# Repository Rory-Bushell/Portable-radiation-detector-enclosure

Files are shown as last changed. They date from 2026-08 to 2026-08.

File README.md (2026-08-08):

# Portable Radiation Detector Enclosure

A rugged, portable enclosure designed to house a Geiger-Müller radiation
sensor (SBM-20) for emergency-response field use — balancing impact and
environmental protection with the need to keep the sensor's detection
window functional.

**Overall dimensions:** 120mm x 170mm x 205mm

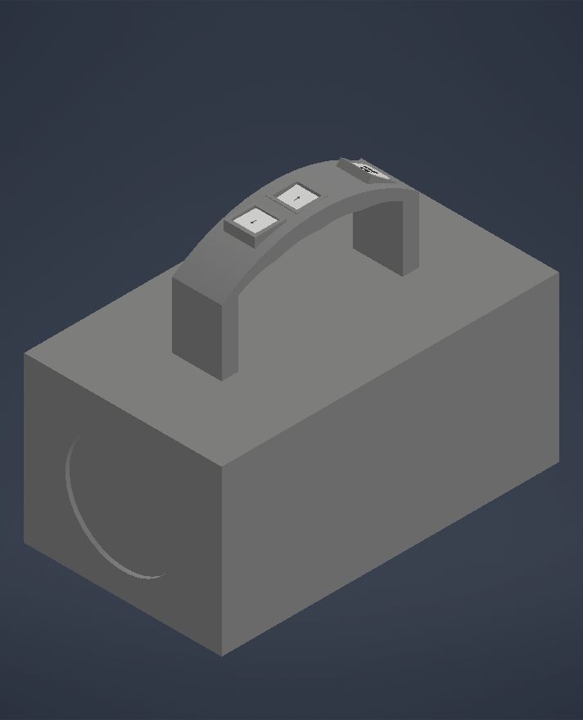
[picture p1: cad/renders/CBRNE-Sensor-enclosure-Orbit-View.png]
Isometric view


## Methodology

| Stage | Method |
|---|---|
| Design requirements | Defined against IP66/67 (environmental sealing), IK-rated impact resistance, and MIL-STD-810G drop-test conventions for portable field equipment |
| Material selection | Granta EduPack Ashby chart comparison — shortlisted candidates for the main shell, sensor window, and threaded cap against density, fracture toughness, temperature, and price constraints |
| CAD design | Autodesk Inventor Professional — full assembly including sealed access hatch, threaded USB-C charging cap with O-ring seal, and internal component layout |
| Packaging validation | Internal layout checked against real component dimensions — SBM-20 tube (108 x 11mm), 50 x 30mm driver PCB, 40 x 30 x 5mm LiPo pouch cell — within an 11.34mm internal clearance constraint |

## Key design decisions

- **1.5mm sensor detection window** (vs. 4mm main shell wall) — minimises
  radiation attenuation directly in front of the sensor, while the rest of
  the shell stays thicker for impact protection. See cross-section render
  below.
- **Threaded USB-C charging cap with O-ring seal**, mounted on the rear face,
  away from the sensor window — keeps the sealed detection face permanently
  undisturbed during charging or servicing
- **LiPo pouch cell over AA batteries** — driven by a strict 11.34mm internal
  clearance constraint; traded field battery-swapping for sealed USB-C
  recharging
- **Consistent polypropylene material family** across the shell, window, and
  cap, differing only in reinforcement type/level — see
  [`materials/material_comparison.md`](materials/material_comparison.md)
  for full Granta EduPack justification

## Environmental sealing

Designed against **IP66/67** (dust-tight, protected against water jets and
temporary immersion) — the standard ingress protection benchmark for
outdoor, field-deployed electronics — using three sealing points:

- **O-ring seal on the sensor window**, bonded into the shell, keeping the
  detection face permanently watertight without relying on a removable joint
- **O-rings under each of the three control buttons**, compressed by the
  button against the shell to seal the button aperture while still allowing
  tactile actuation
- **O-ring seal on the threaded USB-C cap**, compressed as the cap is
  screwed down, sealing the only access point into the electronics
  compartment

Keeping every seal a static, compressed O-ring joint (rather than an
adhesive or gasket-tape seal) means each one can be inspected and, if
necessary, replaced individually without affecting the others.

## Engineering trade-offs

Key constraints encountered during the design, and the decisions made to
address them:

| Constraint | Decision | Trade-off accepted |
|---|---|---|
| Sensor needs radiation reaching it from all sides | Window wall reduced to 1.5mm vs. 4mm shell | Window is the weakest point for impact — mitigated by keeping it small and centrally supported |
| 11.34mm internal clearance between sensor and base | Switched from AA cells to a 40x30x5mm LiPo pouch cell | Lost field battery-swapping; gained a much smaller footprint, recharged via sealed USB-C |
| Cap needs repeated hand-tightening without cross-threading | Coarse M24 x 1.5 ISO metric thread, non-directional glass-mat-reinforced PP | Slightly heavier/less optimised than a fine-pitch thread, but far more tolerant of field handling |
| Sensing element (SBM-20) is a hobbyist-grade component, not an industrial detector | Used as a realistic stand-in, with the limitation stated explicitly (see Note on scope) | Project demonstrates enclosure design methodology rather than detector performance |

## Renders

| View | Description |
|---|---|
| Isometric | Isometric hero view — full assembled enclosure |
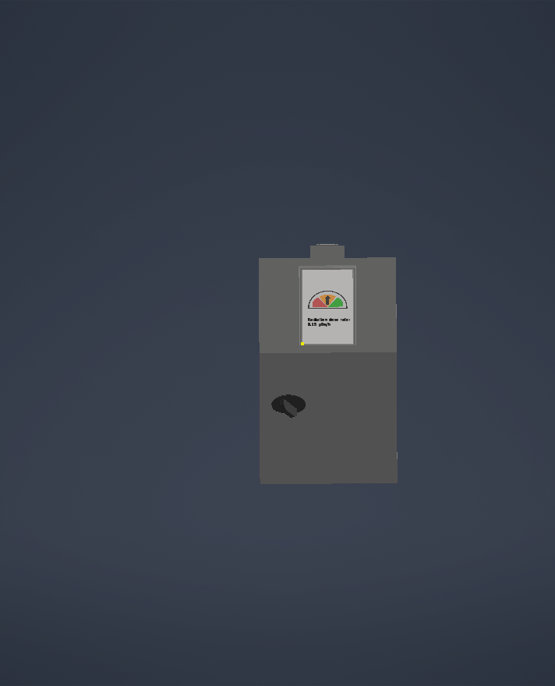
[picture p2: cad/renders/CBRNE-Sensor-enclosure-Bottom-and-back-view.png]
Back and base
|  | Rear/base view — digital display and charging cap |
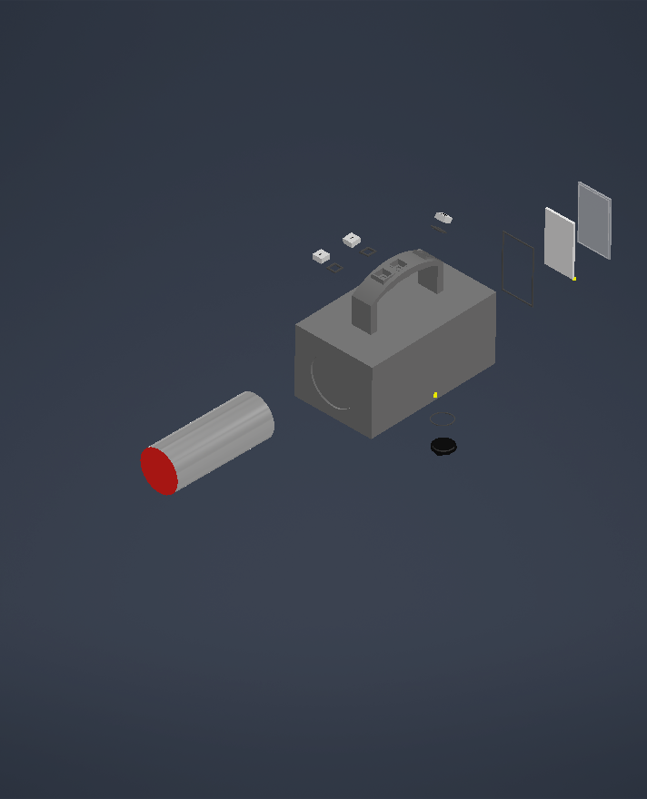
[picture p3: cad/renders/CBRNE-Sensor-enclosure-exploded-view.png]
Exploded view
|  | Exploded assembly — shell, sensor, PCB, battery, cap |
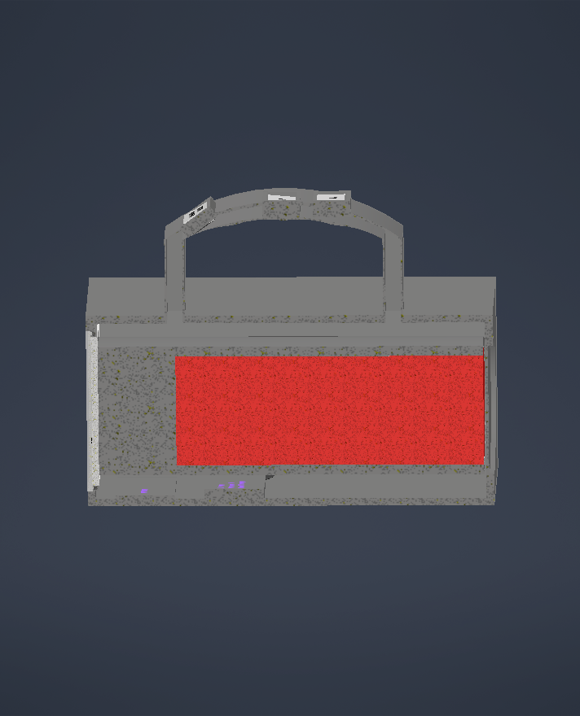
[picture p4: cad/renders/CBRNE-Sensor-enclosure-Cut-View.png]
Cross-section
|  | Cross-section through the sensor window, showing the 1.5mm window wall vs. 4mm shell wall |
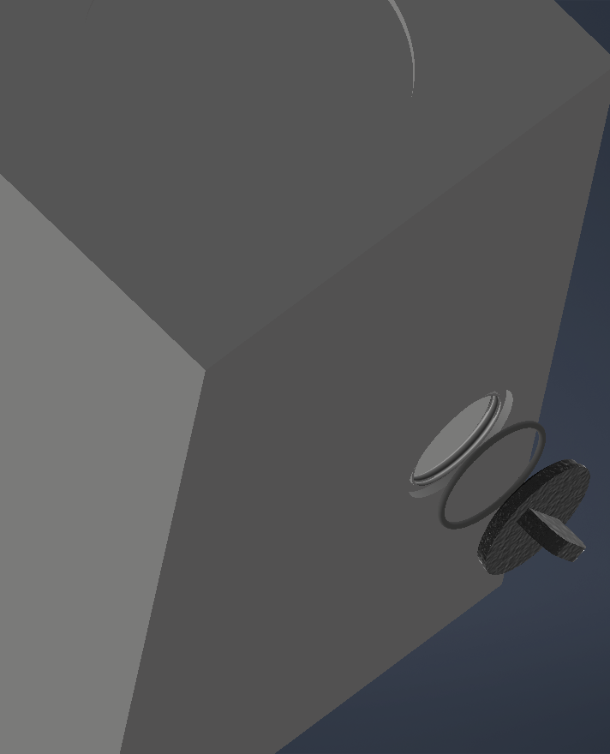
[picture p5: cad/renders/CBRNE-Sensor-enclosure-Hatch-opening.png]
Cap detail
|  | Close-up of the threaded USB-C cap and O-ring seal |

## Materials

Full property data and justification per component:
[`materials/material_comparison.md`](materials/material_comparison.md)

Ashby charts (Fracture Toughness vs. Density) used to shortlist each
component's material — click a link to view the chart at full size:

| Component | Chart |
|---|---|
| Main shell | [View chart](materials/Ashby-chart-Main-Casing.png) |
| Threaded cap | [View chart](materials/Ashby-chart-Opening-hatch.png) |
| Sensor window | [View chart](materials/Ashby-chart-Radiation-window.png) |

## Repository contents

```
cad/
├── CBRNE-sensor-enclosure.stp                  Universally-viewable 3D model
└── renders/
    ├── CBRNE-Sensor-enclosure-Orbit-View.png
    ├── CBRNE-Sensor-enclosure-Bottom-and-back-view.png
    ├── CBRNE-Sensor-enclosure-exploded-view.png
    ├── CBRNE-Sensor-enclosure-Cut-View.png
    └── CBRNE-Sensor-enclosure-Hatch-opening.png
drawings/
└── CBRNE-Sensor-enclosure-Assembly-Drawings.pdf   Dimensioned technical drawing
materials/
├── material_comparison.md                      Granta EduPack property data + justification
├── Ashby-chart-Main-Casing.png
├── Ashby-chart-Opening-hatch.png
└── Ashby-chart-Radiation-window.png
```

**Viewing the STEP file:** GitHub does not render 3D files directly — clicking
the `.stp` file shows raw text. Open it in Inventor, Fusion 360, FreeCAD, or
a free online viewer such as [3dviewer.net](https://3dviewer.net) to view it
interactively.

## Note on scope

This project uses a real, well-documented, low-cost Geiger-Müller tube
(SBM-20) as the sensing element. Industrial radiation portal monitors
typically use scintillator-based detectors (e.g. NaI, plastic scintillators)
meeting standards such as ANSI N42.35 and IEC 62244. The focus of this
project is the mechanical and materials engineering challenge of enclosure
design — protecting a radiation-sensitive component without compromising its
detection capability — not the development of detector technology itself,
and it has not been validated against formal CBRNE testing standards.

## Relevance

Directly engages with radiological detection/sensing technology and
critical infrastructure protection themes, applying materials science
(Granta EduPack) and mechanical design (Inventor) to a real security
engineering constraint: protecting sensitive detection equipment in the
field.

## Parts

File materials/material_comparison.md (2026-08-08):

# Material Selection Summary

Selected via Granta EduPack Level 3 Eco Design database, using a
Fracture Toughness vs. Density Ashby chart methodology, filtered against
component-specific density, fracture toughness, operating temperature bounds, and price constraints.

## Main shell — PP (homopolymer, 30% glass fibre)

| Property | Value |
|---|---|
| Density | 0.0403 – 0.041 lb/in³ |
| Fracture toughness | 2.71 – 4.96 ksi·√in |
| Price | 0.767 – 0.916 USD/lb |

**Justification:** Best combination of low density and high fracture
toughness among candidates passing the shell's constraint set — outperformed
all other options on both axes simultaneously.

## Sensor detection window — PP (homopolymer, clarified/nucleated)

| Property | Value |
|---|---|
| Density | 0.0325 – 0.0328 lb/in³ |
| Fracture toughness | 2.09 – 2.2 ksi·√in |
| Price | 1.01 – 1.3 USD/lb |

**Justification:** Lowest density among viable candidates, prioritising
radiation transparency at the detection face, while retaining adequate
toughness for a thin (1.5mm) protective panel.

## Threaded USB-C cap — PP molding compound (40% random glass mat)

| Property | Value |
|---|---|
| Density | 0.0426 – 0.0434 lb/in³ |
| Fracture toughness | 12.6 – 15.5 ksi·√in |
| Price | 1.63 – 1.89 USD/lb |

**Justification:** Highest fracture toughness among realistic, non-directional
candidates — suited to a small part enduring repeated hand-tightening and
occasional drops.

## Note

All three selected materials are from the polypropylene family, differing
only in reinforcement type/level — a deliberate, consistent material
strategy across the enclosure rather than unrelated material choices per
component.

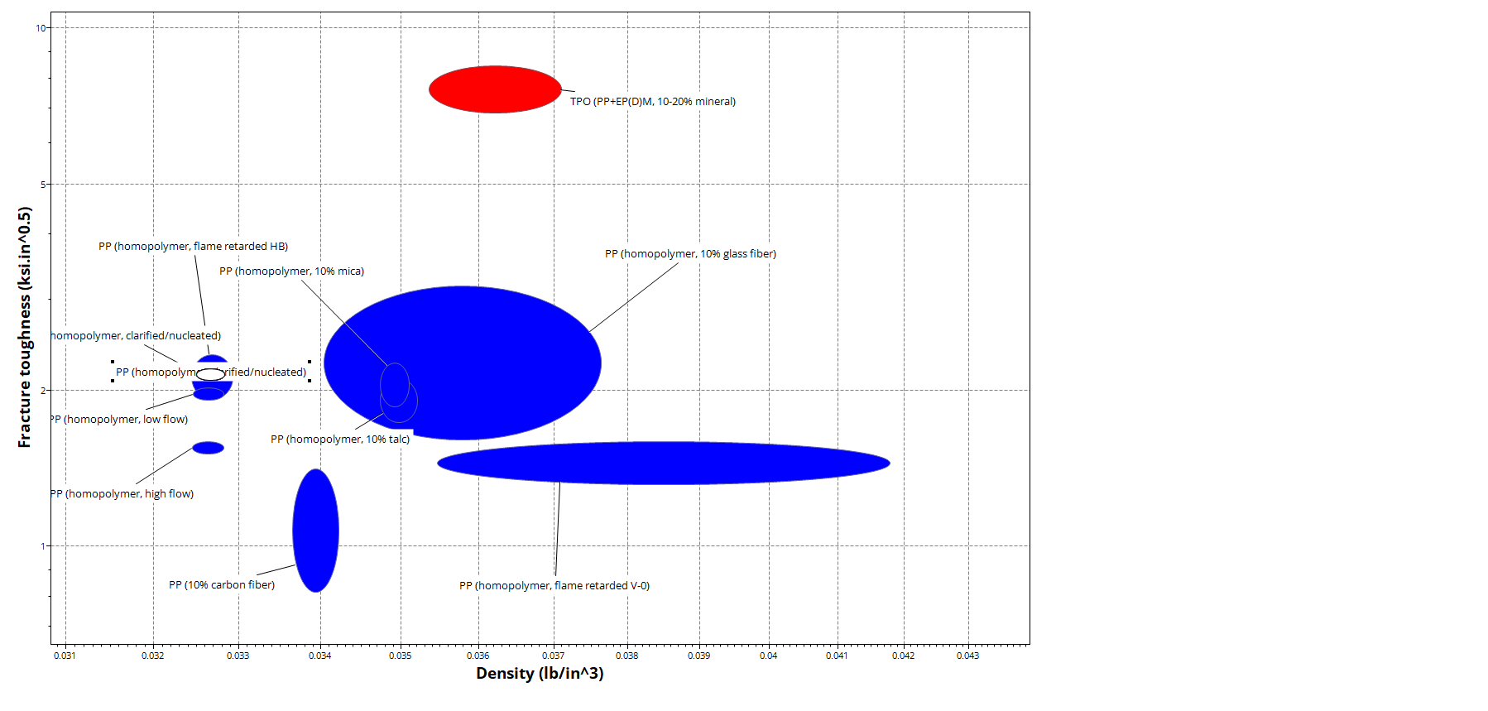
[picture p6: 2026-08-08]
materials/Ashby-chart-Radiation-window.png

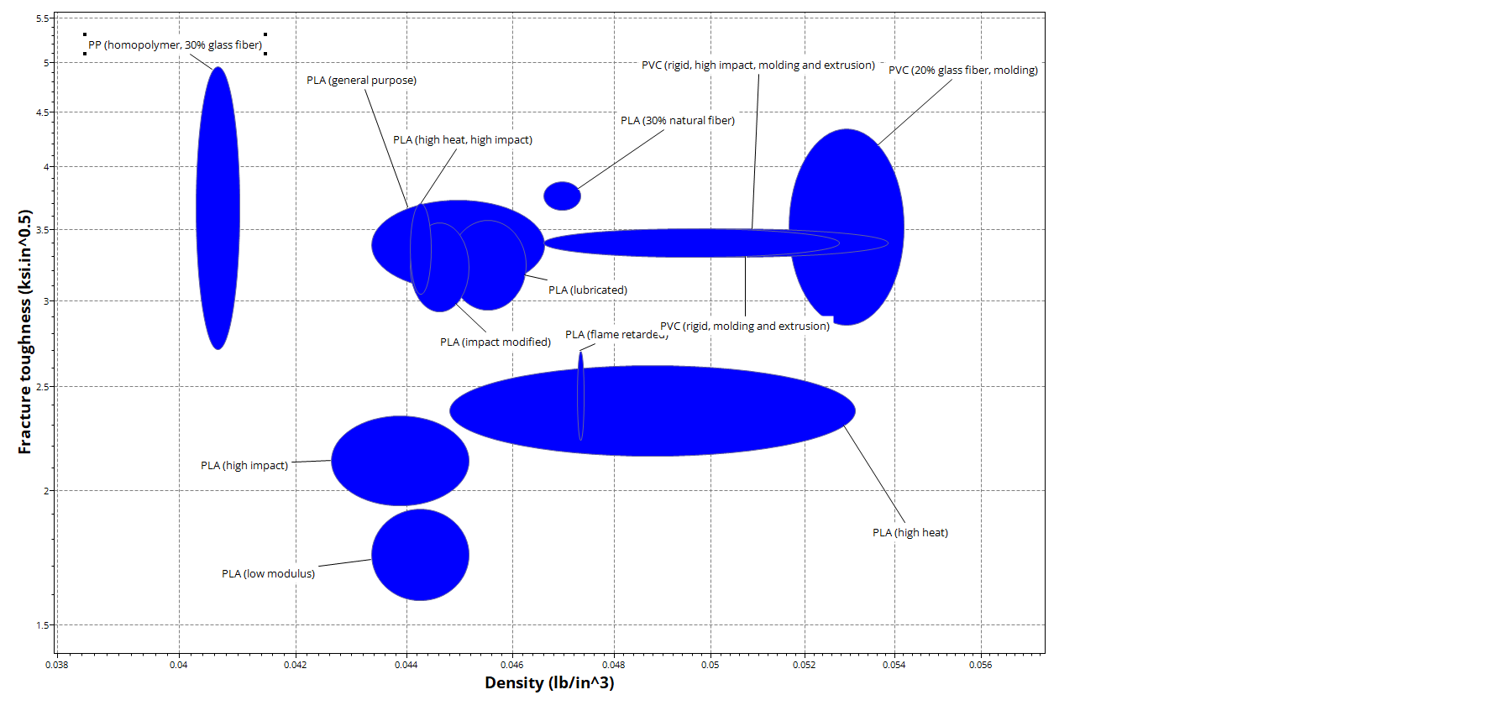
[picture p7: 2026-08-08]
materials/Ashby-chart-Main-Casing.png

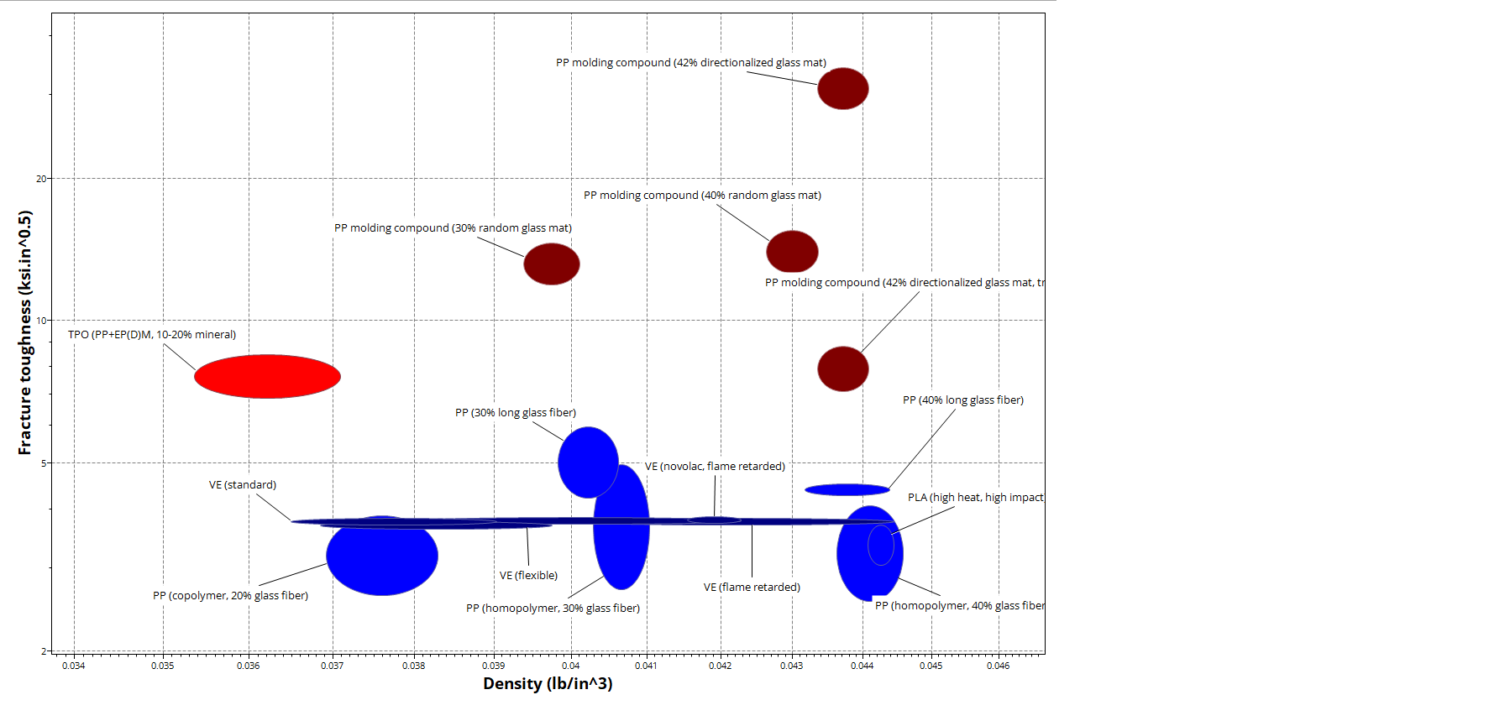
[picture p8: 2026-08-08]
materials/Ashby-chart-Opening-hatch.png

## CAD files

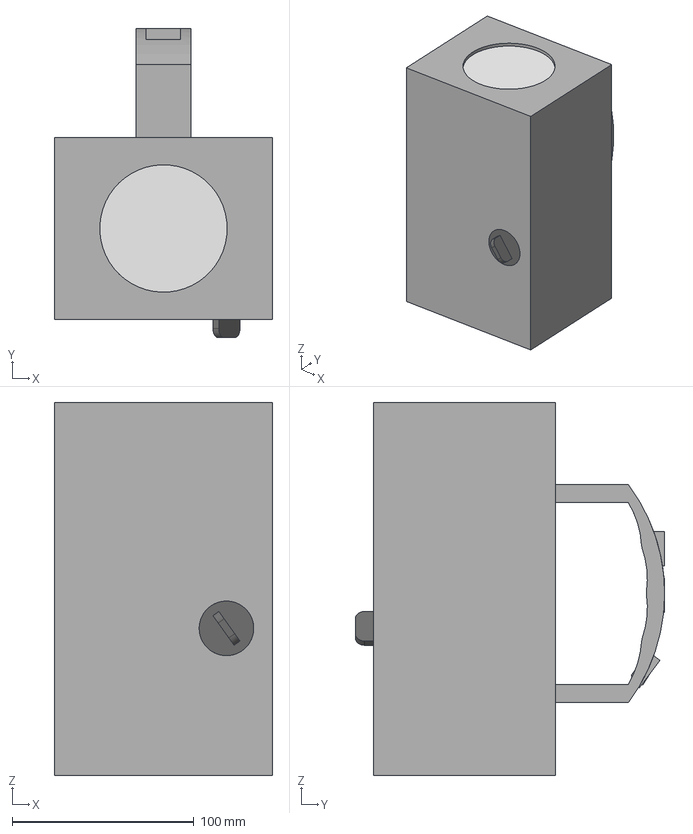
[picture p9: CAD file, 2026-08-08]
cad/CBRNE-sensor-enclosure.stp
120.0 x 170.0 x 205.0 mm
Main casing
Radiation sensor
Electronic screen
Protective glass
O-ring for protective glass
Button x 3
O-Ring for buttons x 3
O-ring for battery hatch
Hatch opening

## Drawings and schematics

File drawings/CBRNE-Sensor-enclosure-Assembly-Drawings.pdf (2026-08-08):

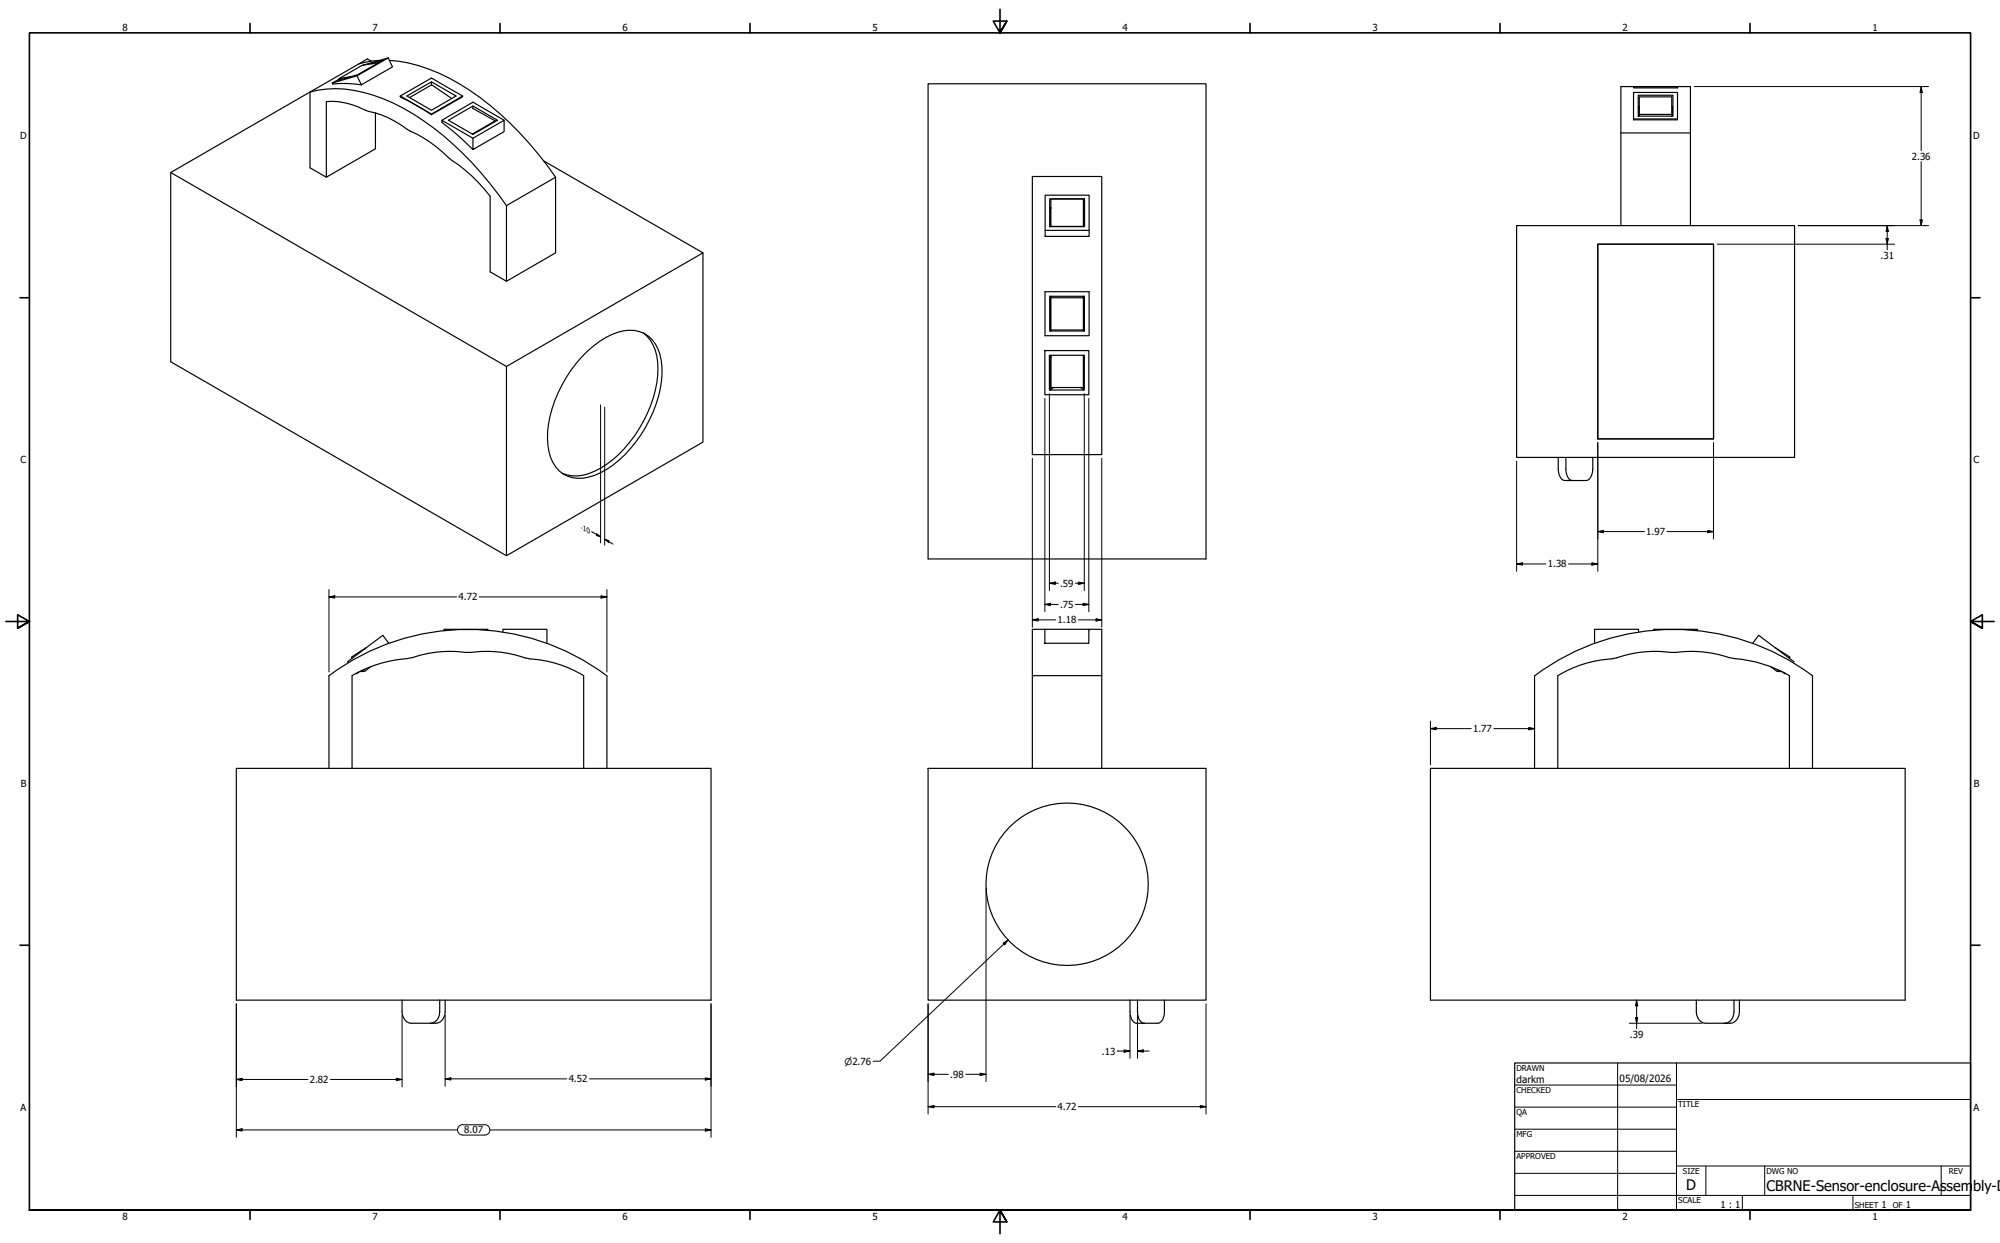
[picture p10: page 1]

DRAWN darkm | 05/08/2026

CHECKED

MFG

APPROVED

SIZE D | DWG NO | REV

CBRNE-Sensor-enclosure-Assembly-D

SCALE 1 : 1 | | SHEET 1 OF 1
